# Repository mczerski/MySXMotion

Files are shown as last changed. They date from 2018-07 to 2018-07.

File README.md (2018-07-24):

# MySXMotion
## MySX Board for motion sensor

This is a multipurpose daughterboard but its main use is for AS312 motion sensor with MySX conector. It also consist of BH1750 ambient light sensor and header for one i2c device, uart and avr ISP. It is meant to be combined with a [MySMotherboard](https://www.openhardware.io/view/606/MySMotherboard) to make fully functional motion sensor node.

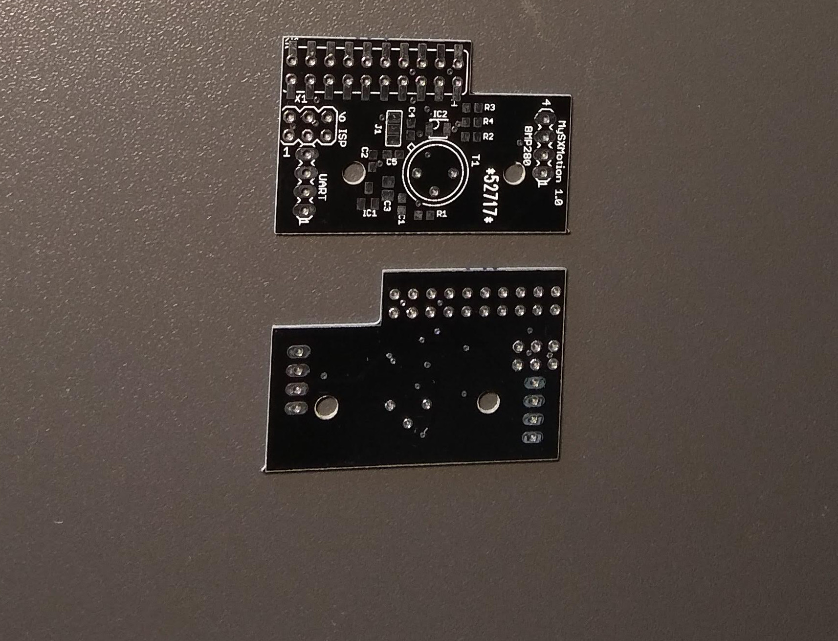
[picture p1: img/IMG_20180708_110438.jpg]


## Features:

1. support for SMD MySX header for low profile connection with MySX motherboard
2. AS312 motion sensor with dedicated LDO
3. BH1750 ambient light sensor
4. I2C header
5. AVR ISP header
6. uart header

## HOW TO
1. Low profile MySX header connector.
The board is designed for smd low profile MySX 2.5 header connector which significantly reduces node size. 
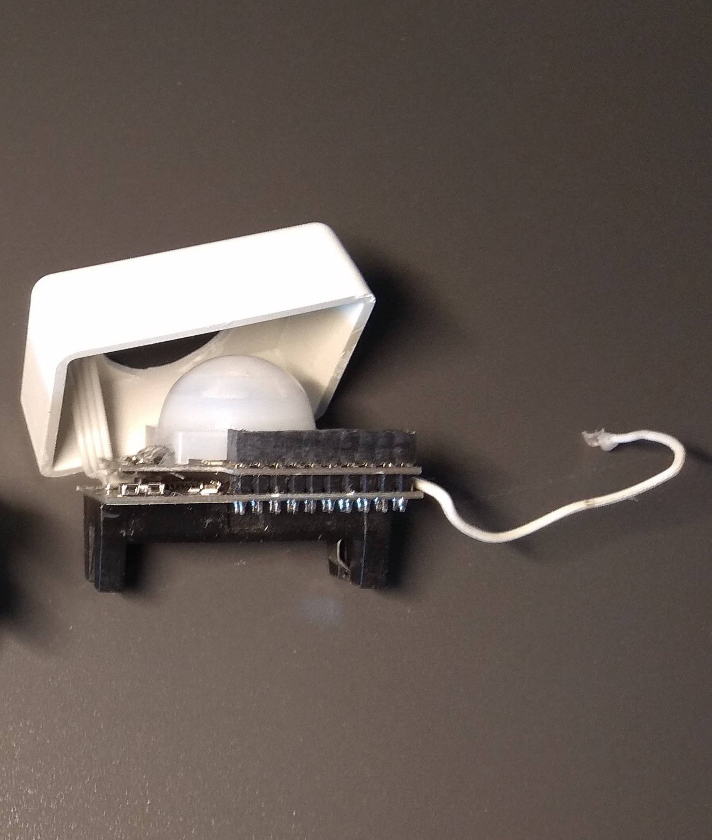
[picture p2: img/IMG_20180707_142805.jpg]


2. AS312 motion sensor
For best performance motion sensor is powered through dedicated low quiescent current 3V LDO. The LDO is powered from MySX VRAW pin, so voltage on this pin must be higer than 3.1V. 3.7V LI-ION rechargable battery would be a good power source solution. The circuit consists also of battery reverse polarity protecion MOSFET.
For motion sensor required components to solder are:
Q1, C1, C2, C3, R1, IC1, IC3

3. BH1750 ambient light sensor
Ambient light sensor is powered from the MySX VCC pin. J2 jumper is used to select I2C addres of the light sensor.
Required components to solder are:
R2, R3, R4, C4, C5, IC2, J1 (choose one of two options)

4. Additional headers
By soldering ISP header this board can be use as a MySX to AVR ISP adapter. To I2C header one additional i2c device can be conected. To UART header one additional uart device can be connected.

## Software
For easy software developement there is available toolkit library that enhance MySensors library called [MySensorsToolkit](https://github.com/mczerski/MySensorsToolkit) and also there is an example sketch [MyMultiSensor](https://github.com/mczerski/MyMultiSensor).
The easies way to use this software is to clone the current version of the Arduino sketchbook [Arduino-MySensors](https://github.com/mczerski/Arduino-MySensors):
```
git clone https://github.com/mczerski/Arduino-MySensors
git submodule update --init
```
and then setup Arduino IDE to point to this folder as a sketchbook.

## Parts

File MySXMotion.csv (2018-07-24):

Part | Value | Package | Description
C1 | 100n | C0603 | Capacitor
C2 | 1u | C0603 | Capacitor
C3 | 1u | C0805 | Capacitor
C4 | 100n | C0603 | Capacitor
C5 | 100n | C0603 | Capacitor
IC1 | XC6206P30 | SOT23 | Voltage Regulators (https://www.torexsemi.com/file/xc6206/XC6206.pdf)
IC2 | BH1750FVI | WSOF6 | Ambient light sensor (https://www.mouser.com/ds/2/348/bh1750fvi-e-186247.pdf)
IC3 | AS312 | TO5 | PIR sensor (http://www.image.micros.com.pl/_dane_techniczne_auto/cz%20as312.pdf)
Q1 | DMP2305U | SOT-23 | P-MOSFET (https://www.diodes.com/assets/Datasheets/ds31737.pdf)
R1 | 10k | R0603 | Resistor
R2 | 4.7k | R0603 | Resistor
R3 | 4.7k | R0603 | Resistor
R4 | 1k | R0603 | Resistor
UART |  |  | 4x1 PIN HEADER
I2C |  |  | 4x1 PIN HEADER
ISP |  |  | 3x2 PIN HEADER
X1 |  |  | 10x2 FEMALE HEADER
J1 |  |  | SMD solder JUMPER

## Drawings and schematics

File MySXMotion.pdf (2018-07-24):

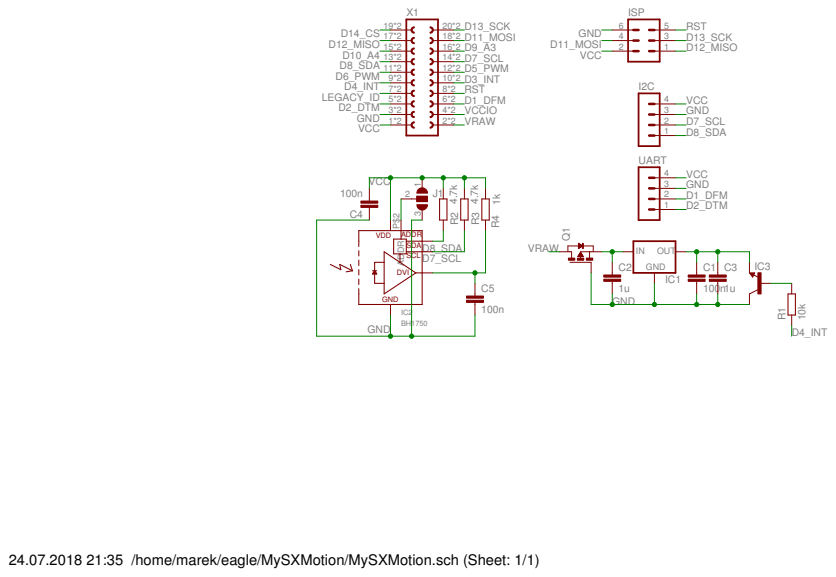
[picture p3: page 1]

24.07.2018 21:35 /home/marek/eagle/MySXMotion/MySXMotion.sch (Sheet: 1/1)

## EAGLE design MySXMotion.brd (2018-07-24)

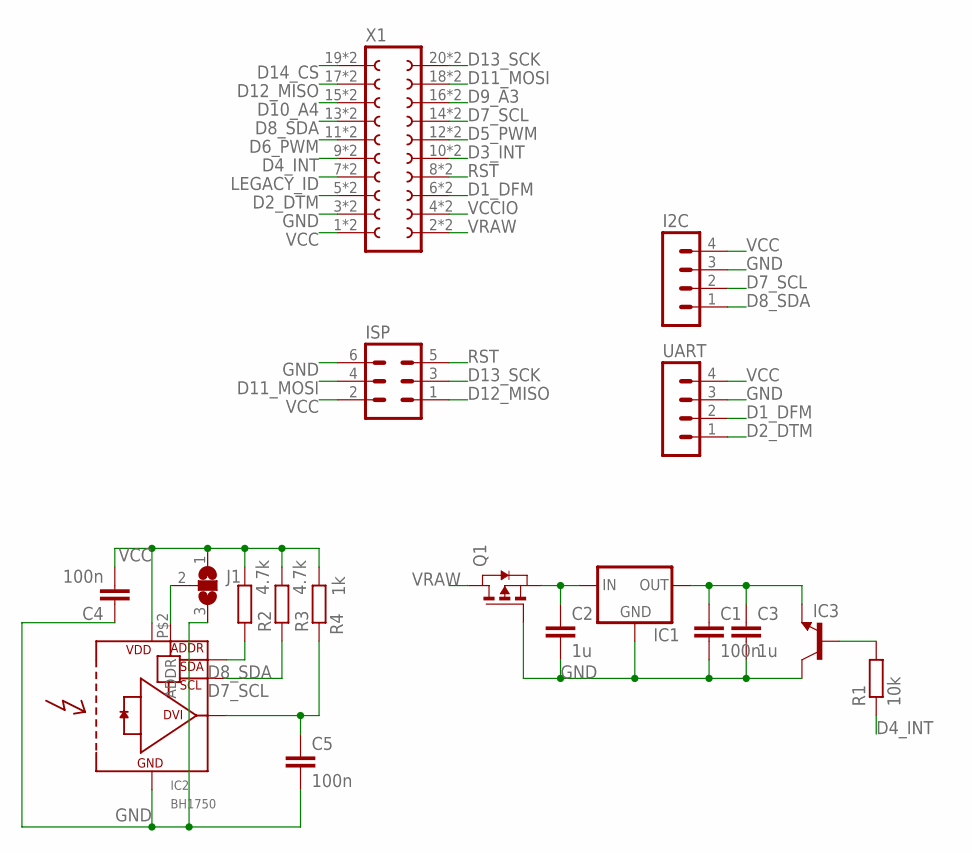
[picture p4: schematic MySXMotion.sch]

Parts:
C1, C4, C5: 100n; C0603
C2: 1u; C0603
C3: 1u; C0805
I2C: MA04-1
IC1: XC63FPM; SOT23
IC2: BH1750; WSOF6
IC3: -NPN-TO5; TO5
ISP: MA03-2
J1: SJ2W; SJ_2
Q1: PMOSSOT23; SOT-23
R1: 10k; R0603
R2, R3: 4.7k; R0603
R4: 1k; R0603
UART: MA04-1
X1: FE10-2

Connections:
D1_DFM: UART.2, X1.6, X1.P$6 (6)
D2_DTM: UART.1, X1.5, X1.P$5 (5)
D3_INT: X1.10, X1.P$10 (10)
D4_INT: R1.1, X1.9, X1.P$9 (9)
D5_PWM: X1.12, X1.P$12 (12)
D6_PWM: X1.11, X1.P$11 (11)
D7_SCL: I2C.2, IC2.P$6 (SCL), R3.1, X1.14, X1.P$14 (14)
D8_SDA: I2C.1, IC2.P$4 (SDA), R2.1, X1.13, X1.P$13 (13)
D9_A3: X1.16, X1.P$16 (16)
D10_A4: X1.15, X1.P$15 (15)
D11_MOSI: ISP.4, X1.18, X1.P$18 (18)
D12_MISO: ISP.1, X1.17, X1.P$17 (17)
D13_SCK: ISP.3, X1.20, X1.P$20 (20)
D14_CS: X1.19, X1.P$19 (19)
GND: C1.2, C2.2, C3.2, C4.1, C5.2, I2C.3, IC1.1 (GND), IC2.P$3 (GND), IC3.3 (C), ISP.6, J1.3, Q1.3 (G), UART.3, X1.3, X1.P$3 (3)
LEGACY_ID: X1.7, X1.P$7 (7)
unnamed: C5.1, IC2.P$5 (DVI), R4.2
unnamed: IC2.P$2 (ADDR), J1.2
unnamed: IC3.2 (B), R1.2
unnamed: C2.1, IC1.3 (IN), Q1.2 (S)
unnamed: C1.1, C3.1, IC1.2 (OUT), IC3.1 (E)
RST: ISP.5, X1.8, X1.P$8 (8)
VCC: C4.2, I2C.4, IC2.P$1 (VCC), ISP.2, J1.1, R2.2, R3.2, R4.1, UART.4, X1.1, X1.P$1 (1)
VCCIO: X1.4, X1.P$4 (4)
VRAW: Q1.1 (D), X1.2, X1.P$2 (2)

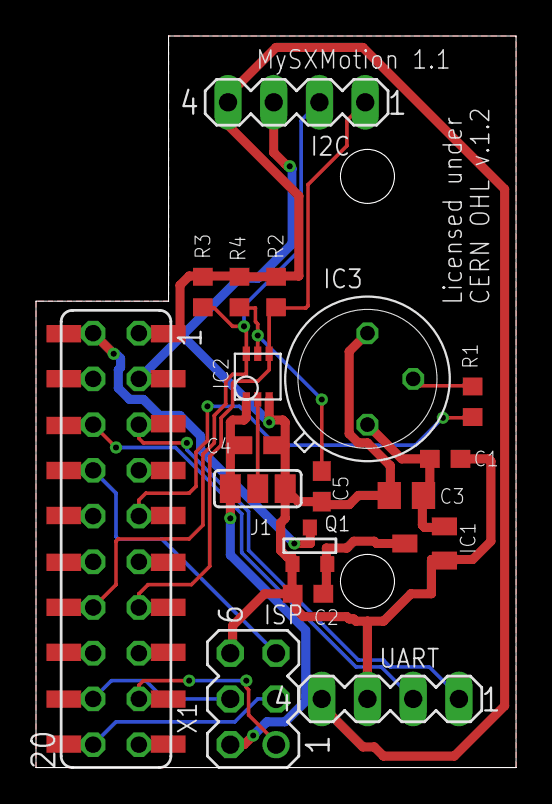
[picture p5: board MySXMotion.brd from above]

Board: 2 copper layers, 26.7 x 40.6 mm, 18 parts (0 on the bottom side), 25 nets.

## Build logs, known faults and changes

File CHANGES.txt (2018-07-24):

Modifications made by Licensee (see section 3.4.b in the LICENSE.txt file)

v1.1 - First public release

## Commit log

2018-06-10 firs version
    [MySXMotion.brd, MySXMotion.sch]
2018-07-07 add reverse voltage protection
    [MySXMotion.brd, MySXMotion.sch]
2018-07-24 add documentation
    [MySXMotion.GBL, MySXMotion.GBO, MySXMotion.GBS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]
2018-07-24 add bom and schematic pdf
    [MySXMotion.csv, MySXMotion.sch]

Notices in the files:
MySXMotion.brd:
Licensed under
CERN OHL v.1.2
